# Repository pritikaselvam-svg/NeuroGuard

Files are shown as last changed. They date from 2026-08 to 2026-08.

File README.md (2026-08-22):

# NeuroGuard[README.md](https://github.com/user-attachments/files/31235367/README.md)
# NeuroGuard --- Wearable Alzheimer's Patient Monitoring & Caregiver Support System

NeuroGuard is an interdisciplinary engineering prototype combining
**biological/behavioral reasoning, embedded electronics, PCB design,
software, Android packaging, and wearable CAD**.
## PCB Design

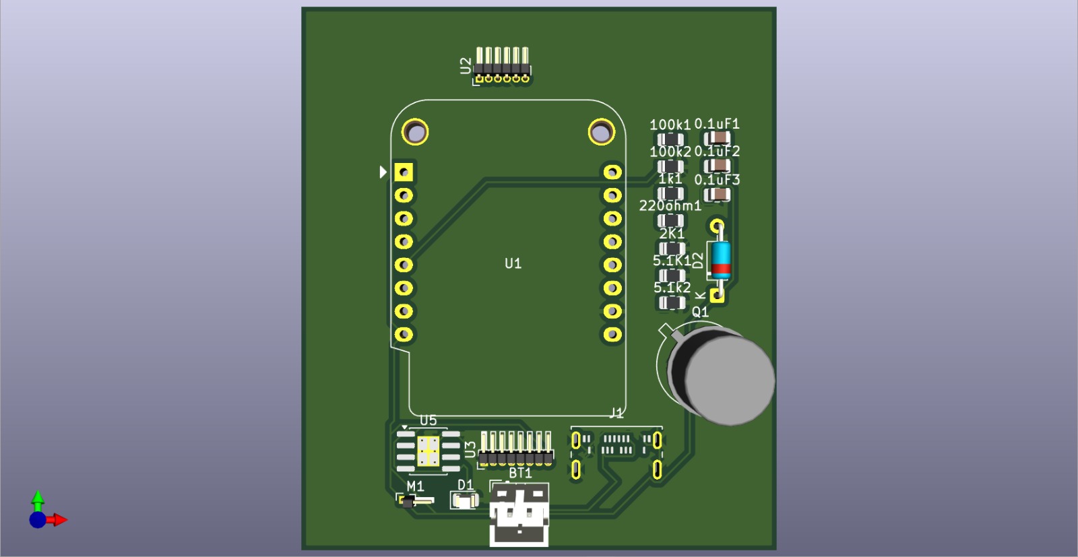
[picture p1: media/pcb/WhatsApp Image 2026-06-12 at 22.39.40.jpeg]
NeuroGuard PCB


> **Current prototype status:** The caregiver application is functional
> in Demo/Simulation Mode. The Android application is a WebView wrapper
> around the HTML/CSS/JavaScript interface. The physical PCB and live
> sensor-to-phone BLE pipeline remain hardware-integration stages.

## What the system is designed to support

-   Heart-rate monitoring using MAX30102.
-   SpO2-related optical measurement capability.
-   Motion/activity monitoring using MPU6050.
-   Fall-event detection logic.
-   Unusual activity / wandering-support logic.
-   Sleep/activity trend estimation.
-   Medication reminders and adherence logging.
-   Haptic alerts through a vibration motor.
-   Battery monitoring.
-   Caregiver dashboard and alerts.

## System architecture

``` text
       BIOLOGICAL / BEHAVIORAL LAYER
                    |
                    v
             Signal selection
                    |
                    v
 MAX30102 ----+                 +---- MPU6050
              |                 |
              +---- ESP32-C3 ---+
                       |
             +---------+---------+
             |         |         |
             v         v         v
          Haptic    Battery     BLE
          Alert     Monitor      |
                                 v
                           Android App
                                 |
                                 v
                          Caregiver UI
```

## Repository structure

``` text
docs/        Research, design decisions, testing and evidence
hardware/    KiCad, Gerbers, BOM and datasheets
firmware/    ESP32-C3 firmware
app/         Web application and Android wrapper
cad/         Wearable enclosure files
data/        Simulated/test data
media/       Portfolio images and diagrams
```

## Important medical boundary

NeuroGuard is a **student engineering prototype, not a medical
diagnostic device**.

The current system must not be described as diagnosing Alzheimer's
disease, infection, dehydration, or another medical condition. In
particular, MAX30102 heart-rate data is a physiological signal, not an
infection detector. The current hardware also does not contain a
dedicated temperature sensor.

## Current versus future implementation

### Current

``` text
Simulated JavaScript data
        ↓
HTML/CSS/JS dashboard
        ↓
Android WebView
```

### Target

``` text
MAX30102 + MPU6050 + battery
             ↓
          ESP32-C3
             ↓
             BLE
             ↓
        Android App
             ↓
       Caregiver UI
```

## Engineering evidence

The repository documents the complete path:

**Problem → research → biological mapping → requirements → component
selection → schematic → PCB → firmware architecture → app → CAD →
testing → limitations → future work.**

## Status

-   [x] Problem definition
-   [x] Biological/behavioral mapping
-   [x] Component selection
-   [x] KiCad schematic
-   [x] PCB routing
-   [x] Web dashboard
-   [x] Simulated sensor layer
-   [x] Android WebView packaging
-   [ ] Physical PCB bring-up
-   [ ] Real sensor validation
-   [ ] ESP32-C3 firmware validation
-   [ ] BLE integration
-   [ ] Enclosure fabrication
-   [ ] Integrated hardware testing
-   [ ] Human/clinical validation

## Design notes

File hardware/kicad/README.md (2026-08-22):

# KiCad Design Files

This folder contains the editable KiCad design files for the NeuroGuard wearable PCB.

## Files

- `NeuroGuard.kicad_sch` — Complete circuit schematic
- `NeuroGuard.kicad_pcb` — PCB layout and routing
- `NeuroGuard.kicad_pro` — KiCad project configuration

## Design

The PCB integrates:

- WEMOS C3 Mini / ESP32-C3
- MAX30102 physiological sensor
- MPU6050 motion sensor
- TP4056 battery charging
- 3.3 V regulation
- Battery voltage monitoring
- Vibration motor driver
- Status LED
- USB-C power input

## Design Verification

The schematic was checked using KiCad Electrical Rules Check (ERC).

The PCB was subsequently routed and checked using KiCad Design Rules Check (DRC).

## Editing

Open the `.kicad_pro` file in KiCad to access the complete project.

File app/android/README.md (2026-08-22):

# NeuroGuard Mobile Application

The NeuroGuard application is the software interface for the wearable Alzheimer's patient monitoring system.

It provides a caregiver-facing dashboard for viewing patient information, monitoring simulated health metrics, identifying abnormal activity and presenting alerts.

> **Current implementation:** The application currently runs using simulated sensor data. Hardware sensor-to-app communication will be integrated in a later stage.

---

## Application Overview

The application is built as a lightweight web-based interface that can also be packaged and deployed as an Android application using Android Studio and a WebView.

The current application consists of:

- HTML — application structure and interface
- CSS — visual design and responsive layout
- JavaScript — application logic and dashboard interactions
- Sensor Service — simulated sensor data generation and processing

---

## Project Files

### `index.html`

The main entry point of the application.

It defines:

- Application layout
- Dashboard structure
- Patient information
- Health metric cards
- Navigation
- Alerts
- Monitoring sections
- Media and visual elements

The HTML file provides the structure that is rendered inside the Android WebView.

---

### `style.css`

Contains the visual styling of the application.

It controls:

- Colours
- Typography
- Cards
- Buttons
- Navigation
- Dashboard layout
- Responsive behaviour
- Spacing
- Icons
- Alerts
- Mobile presentation

The stylesheet allows the same interface to operate as both a web application and a mobile interface.

---

### `app.js`

Contains the main application logic.

Responsibilities include:

- Dashboard updates
- UI interactions
- Navigation
- Updating displayed values
- Alert presentation
- Patient monitoring interface
- Interaction between the interface and sensor data

---

### `sensorService.js`

Handles the sensor-data layer of the application.

Since the physical wearable prototype is currently under development, this service provides **simulated sensor readings** representing the data expected from the wearable.

The simulated data can represent parameters such as:

- Heart rate
- SpO₂
- Activity
- Movement
- Fall events
- Other wearable-derived metrics

This allows the complete application interface and monitoring logic to be demonstrated before the physical ESP32 wearable is connected.

---

# Data Flow

The intended architecture is:

```text
Wearable Sensors
       ↓
   ESP32-C3
       ↓
 Sensor Processing
       ↓
      BLE
       ↓
NeuroGuard Android App
       ↓
Caregiver Dashboard
       ↓
Alerts / Monitoring

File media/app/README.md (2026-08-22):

# app
# NeuroGuard App

NeuroGuard includes a companion mobile application designed to visualize wearable sensor data, monitor patient status and provide caregiver alerts.

## Application Interface

### Dashboard

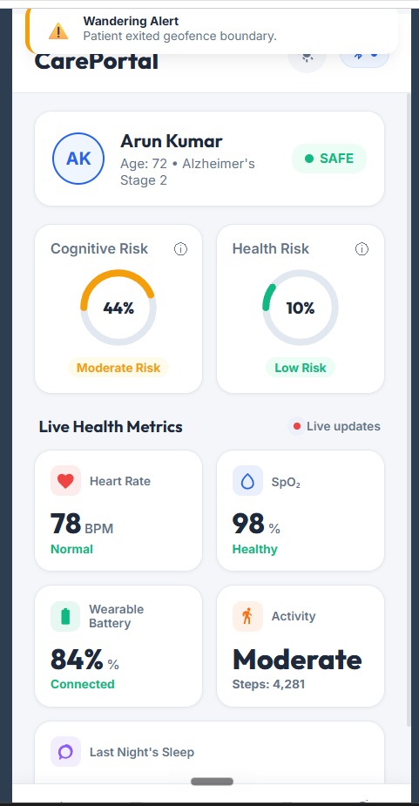
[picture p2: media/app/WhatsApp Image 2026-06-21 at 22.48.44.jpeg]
NeuroGuard App Dashboard


### Patient Monitoring

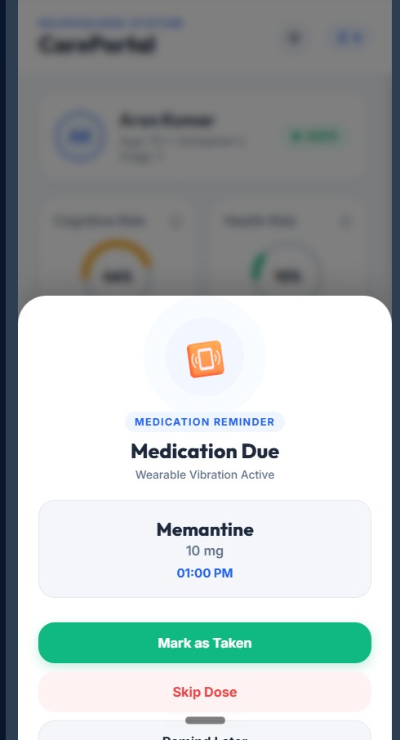
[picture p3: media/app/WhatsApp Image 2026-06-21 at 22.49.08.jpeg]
NeuroGuard Patient Monitoring


### Application Interface

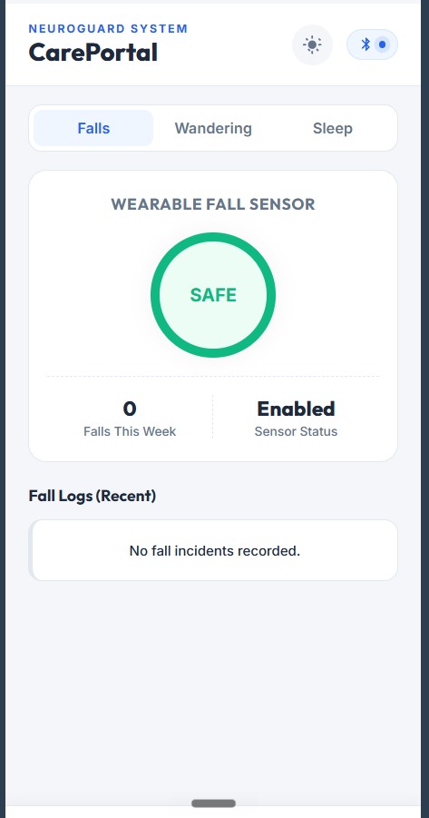
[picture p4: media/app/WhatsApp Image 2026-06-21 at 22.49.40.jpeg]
NeuroGuard App Interface


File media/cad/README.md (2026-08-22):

# cad

# CAD Development

The wearable enclosure was developed with a focus on compactness, component integration, accessibility and comfortable wearable form.

## Modelling Process

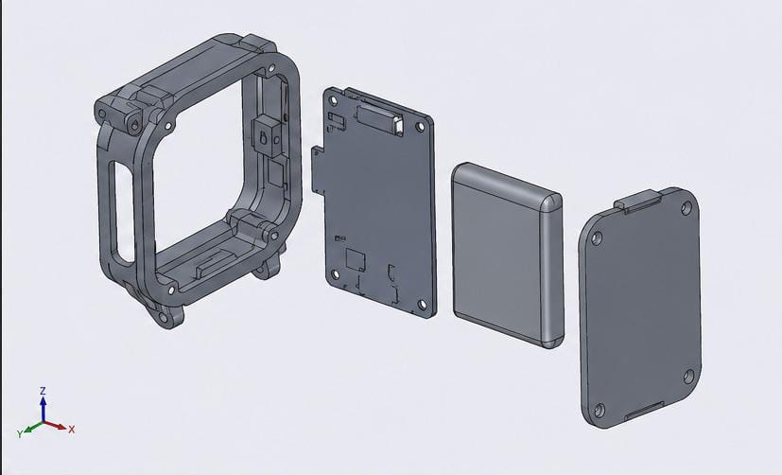
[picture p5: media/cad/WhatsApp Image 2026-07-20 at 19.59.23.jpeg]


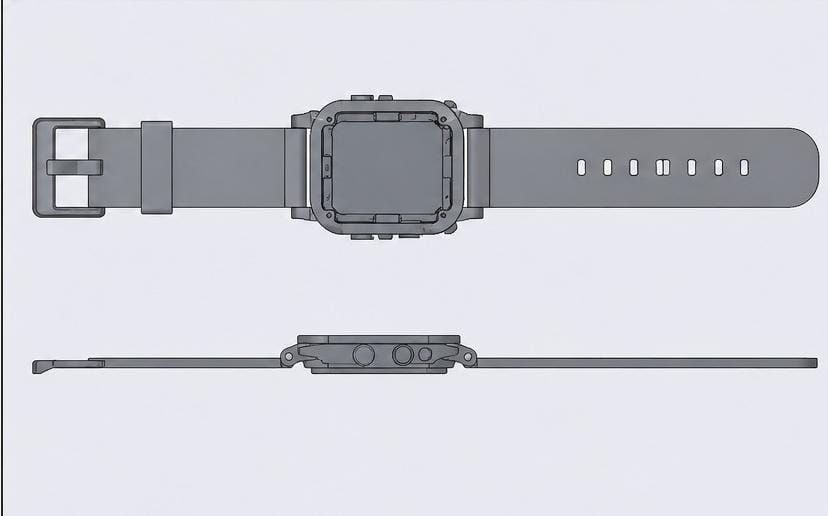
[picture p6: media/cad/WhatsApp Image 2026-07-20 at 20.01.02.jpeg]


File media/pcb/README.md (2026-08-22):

# pcb
# PCB Design

The NeuroGuard PCB integrates the ESP32-C3 Mini, physiological sensing, motion sensing, power management, battery monitoring and wearable alert circuitry into a compact wearable platform.

## PCB Development

### PCB Layout

NeuroGuard PCB Layout

### PCB Routing

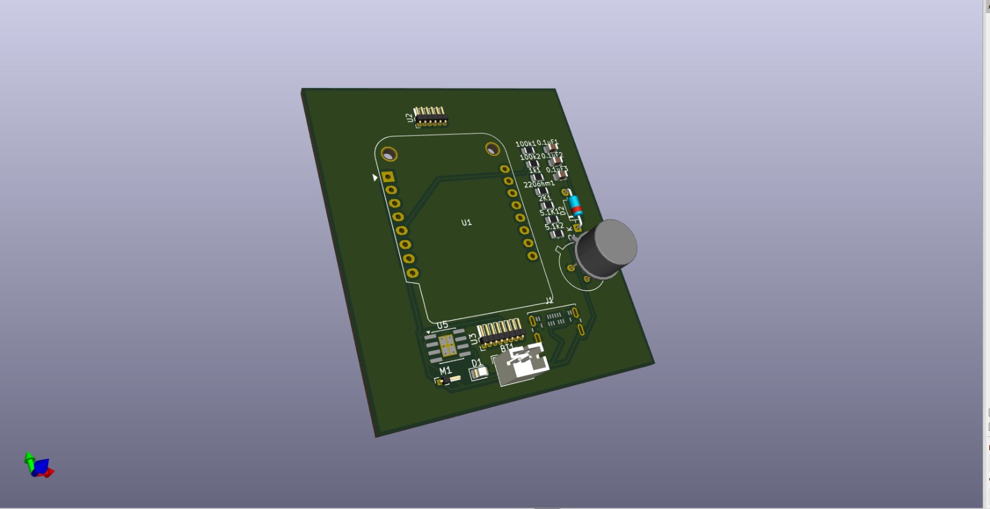
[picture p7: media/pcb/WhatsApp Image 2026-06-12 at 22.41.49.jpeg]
NeuroGuard PCB Routing


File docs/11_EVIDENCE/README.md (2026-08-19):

# Evidence Index

Use this directory for visual proof of development.

``` text
research/    literature and biological mapping
schematic/   KiCad schematic
pcb/         placement, routing, DRC, 3D
firmware/    serial logs and sensor tests
app/         dashboard and Android screenshots
cad/         modelling progression
testing/     measured validation
```

Use descriptive names such as `pcb_05_final_3d.png`, not
`final_final.png`.

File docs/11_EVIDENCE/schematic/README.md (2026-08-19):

# schematic

Add the corresponding project files/evidence here.

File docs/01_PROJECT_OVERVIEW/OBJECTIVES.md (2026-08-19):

# Objectives

## Primary

1.  Design a compact wearable electronics architecture.
2.  Integrate MAX30102 and MPU6050 with an ESP32-C3.
3.  Provide haptic feedback.
4.  Monitor battery voltage.
5.  Develop a caregiver-facing application.
6.  Build a simulated-data pipeline for software validation.
7.  Document the complete engineering process.

## Secondary

-   Keep the architecture low-cost and modular.
-   Minimize wearable volume.
-   Separate sensor drivers from decision logic.
-   Make simulation replaceable by live BLE data.

## Explicit non-objectives

-   Alzheimer's diagnosis.
-   Infection diagnosis.
-   Clinical treatment decisions.
-   Claims of clinical accuracy without validation.

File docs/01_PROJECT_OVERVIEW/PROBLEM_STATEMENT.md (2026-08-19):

# Problem Statement

People living with Alzheimer's disease and related cognitive impairment
may experience changes in movement, sleep/activity patterns, falls,
physiological state and medication adherence. Caregivers may not
continuously observe these changes.

There is an opportunity to explore a compact, low-cost wearable that
combines multiple sensing modalities with caregiver-facing software.

**NeuroGuard proposes a wearable monitoring prototype that integrates
optical physiological sensing, motion sensing, battery monitoring,
haptic feedback and a caregiver application.**

The engineering problem is to convert low-level sensor measurements into
understandable, actionable caregiver information while maintaining a
clear distinction between measurement, inference and medical diagnosis.

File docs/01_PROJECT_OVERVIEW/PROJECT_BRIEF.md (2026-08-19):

# Project Brief

## Concept

NeuroGuard is a compact wearable concept intended to provide caregivers
with continuous observations of selected physiological and movement
signals while supporting medication reminders and event alerts.

## Intended users

-   People living with Alzheimer's disease or related cognitive
    impairment.
-   Family caregivers.
-   Professional caregivers.
-   Student/research teams exploring assistive-health technology.

## Core problem

A caregiver cannot continuously observe a patient's movement,
sleep/activity pattern, physiological state, or medication response. A
wearable can provide an additional stream of observations and alerts.

## Proposed solution

A wrist-worn device combines:

-   WEMOS C3 Mini / ESP32-C3.
-   MAX30102 optical sensor.
-   MPU6050 accelerometer/gyroscope.
-   Battery monitor.
-   Vibration motor.
-   Status LED.
-   Rechargeable Li-ion power system.

The companion application presents the resulting information in a
caregiver-oriented interface.

## Design philosophy

NeuroGuard is a **support system**, not a diagnostic system. It reports
observations, trends and event candidates and clearly identifies
uncertainty.

## Demonstration strategy

Because the physical sensor-to-app pipeline is not yet complete, the
software uses deterministic/randomized simulated values to demonstrate
the complete user workflow before hardware integration.

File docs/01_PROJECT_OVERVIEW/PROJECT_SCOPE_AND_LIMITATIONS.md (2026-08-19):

# Project Scope and Limitations

## In scope

-   Biological/behavioral signal mapping.
-   Sensor selection.
-   Electronics and PCB.
-   Embedded architecture.
-   Haptic feedback.
-   Battery monitoring.
-   Caregiver software.
-   Simulated-data validation.
-   Wearable CAD.

## Current limitations

1.  The app currently uses simulated data.
2.  Real BLE communication is not yet validated.
3.  Physical sensor accuracy has not been established.
4.  Battery life has not been characterized.
5.  No clinical dataset has been used.
6.  No clinical thresholds have been validated.
7.  The current hardware has no temperature sensor.
8.  The enclosure is a prototype concept until physically fabricated.

## Interpretation

A feature is marked **implemented** only when it is actually
demonstrated. A feature marked **planned** must not be presented as a
completed hardware capability.

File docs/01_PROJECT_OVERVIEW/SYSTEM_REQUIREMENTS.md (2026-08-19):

# System Requirements

  ID      Requirement                          Verification
  ------- ------------------------------------ ---------------------
  FR-01   Acquire optical physiological data   Sensor test
  FR-02   Acquire motion data                  IMU test
  FR-03   Process signals using ESP32-C3       Firmware test
  FR-04   Provide haptic notification          Motor test
  FR-05   Monitor battery voltage              ADC test
  FR-06   Support medication reminders         App test
  FR-07   Display trends and alerts            App test
  FR-08   Operate in Demo Mode                 Software test
  FR-09   Define a future BLE interface        Architecture review

## Physical constraints

-   Wrist-worn form factor.
-   Rechargeable single-cell Li-ion.
-   Compact PCB.
-   Sensor-to-skin access.
-   Accessible charging.
-   Safe battery enclosure.

## Safety

The prototype must not be used as a medical decision-making system.
Electrical safety and battery protection must be verified before
physical use.

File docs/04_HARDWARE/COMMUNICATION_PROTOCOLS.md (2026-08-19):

# Communication Protocols

## Current

The app uses local simulated JavaScript data. Live BLE has not yet been
validated.

## Target

``` text
ESP32-C3 → BLE → Android
```

## Suggested data packet

``` json
{
  "timestamp": 0,
  "heartRate": 78,
  "spo2": 98,
  "activity": 0.42,
  "fall": false,
  "battery": 84
}
```

The final BLE UUIDs, packet format and update rate should be defined
before live integration.

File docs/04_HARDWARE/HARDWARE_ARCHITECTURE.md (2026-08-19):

# Hardware Architecture

``` text
USB-C
  ↓
TP4056
  ↓
1-cell Li-ion
  ↓
RT9701
  ↓
3.3 V
  ├── ESP32-C3
  ├── MAX30102
  └── MPU6050

ESP32-C3
  ├── Battery ADC
  ├── Status LED
  ├── 2N2219 → vibration motor
  └── Future BLE
```

## Design intent

The WEMOS C3 Mini is the controller. MAX30102 provides optical sensing.
MPU6050 provides motion sensing. The power stage provides a rechargeable
supply. The motor is driven through a transistor rather than directly
from a GPIO.

## Hardware validation boundary

The architecture is a design artifact until the physical board is
powered and each subsystem is measured.

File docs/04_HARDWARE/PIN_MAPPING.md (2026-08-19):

# Pin Mapping

> The final KiCad schematic is the source of truth. Verify GPIO numbers
> against the exact WEMOS C3 Mini board revision before firmware freeze.

  Function        Current schematic role    Peripheral
  --------------- ------------------------- -------------------------
  I2C SDA         Assigned in schematic     MAX30102 + MPU6050
  I2C SCL         Assigned in schematic     MAX30102 + MPU6050
  Battery ADC     D0 in current schematic   100 kΩ / 100 kΩ divider
  Motor control   Assigned GPIO             1 kΩ → 2N2219
  Status LED      Assigned GPIO             220 Ω → LED
  3.3 V           3V3                       Sensors
  Ground          GND                       Common return

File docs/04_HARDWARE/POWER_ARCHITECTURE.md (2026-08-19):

# Power Architecture

``` text
USB-C VBUS
   ↓
TP4056 charger
   ↓
Li-ion battery
   ↓
RT9701
   ↓
3.3 V rail
```

## Battery divider

Current schematic concept:

``` text
Battery +
   |
100 kΩ
   |
   +---- ADC
   |
100 kΩ
   |
  GND
```

The ADC sees approximately half the battery voltage.

### Validation

Before hardware use, verify:

-   ADC input range.
-   Exact ESP32-C3 ADC behavior.
-   Resistor tolerance.
-   Regulator input range.
-   Peak motor current.
-   Battery protection.
-   Charging configuration.

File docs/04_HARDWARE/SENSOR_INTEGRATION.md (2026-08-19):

# Sensor Integration

## I2C

MAX30102 and MPU6050 can share the I2C bus if their addresses and
electrical requirements are compatible.

``` text
ESP32 SDA ──┬── MAX30102 SDA
            └── MPU6050 SDA

ESP32 SCL ──┬── MAX30102 SCL
            └── MPU6050 SCL
```

Both share 3.3 V and GND.

## Integration sequence

1.  Power rails.
2.  I2C initialization.
3.  Bus scan.
4.  MAX30102 initialization.
5.  MPU6050 initialization.
6.  Raw-data read.
7.  Plausibility check.
8.  Feature extraction.
9.  Event logic.
10. Communication.

A successful I2C read does not prove sensor accuracy.

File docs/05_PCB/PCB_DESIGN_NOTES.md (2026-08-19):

# PCB Design Notes

## Subsystems

-   ESP32-C3 module.
-   MAX30102.
-   MPU6050.
-   USB-C charging.
-   TP4056.
-   Li-ion battery.
-   3.3 V regulation.
-   Battery ADC.
-   Haptic driver.
-   Status LED.

## Layout priorities

1.  Compact wearable footprint.
2.  Practical sensor placement.
3.  Short sensitive signal paths.
4.  Local decoupling.
5.  Compact motor-current path.
6.  Accessible charging connection.
7.  Manufacturable clearances.

## Final review

-   [ ] Exact footprints verified.
-   [ ] Board outline verified.
-   [ ] Silkscreen checked.
-   [ ] DRC checked.
-   [ ] Gerbers generated.
-   [ ] Drill files generated.
-   [ ] BOM generated.

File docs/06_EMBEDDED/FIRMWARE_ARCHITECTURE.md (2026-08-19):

# Firmware Architecture

``` text
BOOT
 ↓
GPIO
 ↓
I2C
 ↓
MAX30102 + MPU6050
 ↓
Battery ADC
 ↓
BLE initialization
 ↓
Sensor acquisition
 ↓
Filtering/features
 ↓
Event logic
 ↓
Haptic/LED
 ↓
BLE packet
 ↓
Repeat
```

Recommended modules:

``` text
main
sensor_max30102
sensor_mpu6050
battery
alerts
motor
status_led
ble
data_model
```

Keep hardware drivers separate from event logic.

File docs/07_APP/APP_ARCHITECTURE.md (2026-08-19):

# Application Architecture

``` text
index.html
  ├── style.css
  ├── app.js
  └── sensor.js
          ↓
   simulated data layer
          ↓
      app state
          ↓
          UI
```

Android wrapper:

``` text
MainActivity.kt
      ↓
    WebView
      ↓
file:///android_asset/index.html
```

Future:

``` text
BLE → SensorDataService → App State → UI
```

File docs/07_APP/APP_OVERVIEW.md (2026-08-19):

# Application Overview

The NeuroGuard caregiver app is a mobile-friendly HTML/CSS/JavaScript
interface.

## Main features

-   Patient dashboard.
-   Live-style health metrics.
-   Cognitive-risk visualization.
-   Health-risk visualization.
-   Fall events.
-   Activity/wandering-support events.
-   Sleep/activity trends.
-   Medication management.
-   Alert center.
-   Caregiver information.
-   Device status.

## Demo mode

The app generates simulated values so that the user experience can be
demonstrated before live hardware integration.

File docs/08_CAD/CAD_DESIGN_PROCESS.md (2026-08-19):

# CAD Design Process

## Goal

Create a compact wrist-worn enclosure for the PCB, battery, sensors,
motor and strap.

## Process

``` text
Requirements
→ PCB envelope
→ component packaging
→ outer form
→ sensor contact
→ battery cavity
→ motor clearance
→ back cover
→ strap interface
→ assembly check
```

## Design evidence

Upload actual modelling screenshots showing the progression. Concept
renders should be labelled as concept visuals.

## Key constraints

-   PCB dimensions.
-   Battery thickness.
-   Sensor-to-skin contact.
-   Motor clearance.
-   USB access.
-   Assembly.
-   Strap geometry.
-   Comfort.

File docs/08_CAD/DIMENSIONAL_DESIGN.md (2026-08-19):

# Dimensional Design

Record final dimensions from actual components:

-   PCB length/width/thickness.
-   Battery length/width/thickness.
-   Motor diameter/height.
-   Sensor clearance.
-   Wall thickness.
-   Standoff height.
-   Strap width.

Do not label estimated CAD dimensions as manufacturing-ready dimensions.

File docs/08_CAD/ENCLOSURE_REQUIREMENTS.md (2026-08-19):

# Enclosure Requirements

  Requirement              Reason
  ------------------------ --------------------
  Compact                  Wearability
  Rounded edges            Comfort
  Sensor contact/opening   Optical sensing
  PCB standoffs            Mechanical support
  Battery clearance        Safety
  Motor clearance          Vibration
  Charging access          Usability
  Strap attachment         Retention
  Serviceability           Iteration

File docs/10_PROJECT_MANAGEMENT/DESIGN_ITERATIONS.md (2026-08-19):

# Design Iterations

### Iteration 1

Wearable concept for Alzheimer's caregiver support.

### Iteration 2

Selected MAX30102, MPU6050 and ESP32-C3.

### Iteration 3

Added TP4056, Li-ion battery, RT9701 and battery monitoring.

### Iteration 4

Added transistor-driven vibration motor and status LED.

### Iteration 5

Built software around simulated sensor data.

### Iteration 6

Packaged the web app as an Android WebView.

### Next

Physical bring-up → firmware → BLE → live data → enclosure validation.

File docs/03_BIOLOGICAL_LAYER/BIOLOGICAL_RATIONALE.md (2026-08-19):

# Biological Rationale

NeuroGuard starts from the question: **what caregiver-relevant changes
can be observed non-invasively?**

``` text
Patient physiology/behavior
        ↓
Observable signal
        ↓
Sensor
        ↓
Feature
        ↓
Event/trend
        ↓
Caregiver information
```

### Movement

Acceleration and angular velocity can represent activity and sudden
events.

### Heart rate

Pulse rate is a measurable physiological variable but is highly
non-specific.

### SpO2-related measurement

The MAX30102 provides optical signals from which pulse and
oxygen-saturation-related estimates can be produced. Accuracy must be
validated before clinical interpretation.

### Medication adherence

The current system treats adherence as a software event: reminder →
response → log.

### Infection-related monitoring

The current hardware does not contain a temperature sensor. Therefore it
cannot claim temperature measurement or infection detection. Heart-rate
elevation is only an indirect physiological indicator.

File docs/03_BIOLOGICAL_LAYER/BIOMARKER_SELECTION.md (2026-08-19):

# Signal / Biomarker Selection

  --------------------------------------------------------------------------
  Signal            Rationale            Sensor            Limitation
  ----------------- -------------------- ----------------- -----------------
  Heart rate        Non-invasive         MAX30102          Non-specific
                    physiological                          
                    observation                            

  SpO2-related      Additional           MAX30102          Requires
  optical signal    physiological                          validation
                    context                                

  Acceleration      Activity/fall events MPU6050           False positives
                                                           possible

  Gyroscope         Orientation/motion   MPU6050           Drift/noise
                    context                                

  Battery voltage   Device reliability   Divider + ADC     Calibration
                                                           required

  Medication        Adherence support    App               Self/caregiver
  response                                                 reported
  --------------------------------------------------------------------------

The selection principle is: **every sensor must answer a defined
question.**

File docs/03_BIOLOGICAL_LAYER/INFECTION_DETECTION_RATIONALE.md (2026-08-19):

# Infection-Related Monitoring Rationale

## Current position

NeuroGuard should **not** be described as an infection detector.

The current hardware has MAX30102 but no dedicated temperature sensor.
Heart-rate elevation is non-specific and may have many causes.

### Preferred wording

Use:

-   "physiological change alert"
-   "possible health deterioration"
-   "elevated heart-rate indicator"

Avoid:

-   "infection detected"
-   "infection diagnosis"
-   "fever detected"

unless a validated temperature sensor is actually integrated and
appropriately evaluated.

## Future extension

A future revision may add skin-contact temperature sensing, but
temperature alone would still not establish infection.

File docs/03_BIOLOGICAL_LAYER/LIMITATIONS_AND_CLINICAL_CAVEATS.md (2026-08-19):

# Clinical Caveats and Limitations

1.  NeuroGuard is not a medical device.
2.  No diagnosis is produced.
3.  Heart rate is non-specific.
4.  SpO2 estimates require validation.
5.  Motion-based events can produce false positives/negatives.
6.  Wandering classification requires context and ideally location
    information.
7.  Sleep is currently an activity proxy.
8.  Medication adherence is recorded through a software workflow.
9.  Infection is not detected by the current sensor set.
10. Human testing requires appropriate safety, ethics and consent
    procedures.

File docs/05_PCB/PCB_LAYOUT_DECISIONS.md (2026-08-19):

# PCB Layout Decisions

The WEMOS C3 Mini is the main placement anchor because of its module
size and antenna/keep-out considerations.

The optical sensor should be positioned to permit skin contact. The
MPU6050 should be mechanically stable to produce predictable motion
data.

Power components are grouped around USB-C, charging and regulation. The
vibration motor driver should have a compact high-current path and
should be kept away from the most sensitive sensor area where practical.

The final enclosure must be checked against the actual assembled PCB,
not only the schematic.

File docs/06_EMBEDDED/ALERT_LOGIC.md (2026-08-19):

# Alert Logic

  Event                  Source         Output
  ---------------------- -------------- -----------------
  Medication reminder    App schedule   Vibration + app
  Fall candidate         MPU6050        Alert
  Unusual activity       MPU6050        Flag
  Physiological change   MAX30102       Flag
  Low battery            ADC            Warning

Alerts should eventually have severity levels and an acknowledgement
workflow.

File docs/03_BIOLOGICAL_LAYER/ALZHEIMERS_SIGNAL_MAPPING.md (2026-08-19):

# Alzheimer's Signal Mapping

## Wandering support

``` text
Motion samples
→ activity intensity
→ time-of-day context
→ unusual movement pattern
→ caregiver flag
```

## Fall candidate

``` text
Acceleration
→ spike
→ orientation change
→ post-event inactivity
→ candidate fall
```

## Sleep/activity proxy

``` text
Night-time movement
→ activity windows
→ nightly trend
```

## Physiological observation

``` text
Optical waveform
→ pulse estimate
→ HR trend
→ deviation flag
```

## Medication

``` text
Schedule
→ haptic reminder
→ response
→ adherence record
```

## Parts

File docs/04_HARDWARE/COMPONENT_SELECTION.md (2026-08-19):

# Component Selection

  Ref   Selected part          Purpose                          Why
  ----- ---------------------- -------------------------------- ----------------------------
  U1    WEMOS C3 Mini          MCU/wireless                     Compact ESP32-C3 platform
  U2    MAX30102               Optical sensing                  HR/SpO2-related sensing
  U3    MPU6050                Motion                           Accelerometer + gyroscope
  U5    TP4056-42-ESOP8        Charging                         Single-cell Li-ion charger
  U6    RT9701                 Regulation                       3.3 V rail
  Q1    2N2219                 Motor switch                     Low-side switching
  M1    Coin vibration motor   Haptic                           Compact feedback
  D1    LED                    Status                           Visual indication
  D2    1N4148                 Flyback path in current design   Compact diode
  J1    USB-C power-only       Charging input                   Compact
  BT1   1-cell Li-ion          Energy                           Rechargeable

### Footprint rule

Before fabrication, compare every footprint against the exact purchased
component mechanical drawing.

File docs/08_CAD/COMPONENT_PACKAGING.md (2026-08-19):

# Component Packaging

## Packaging concept

``` text
Skin-facing
└── Optical sensor contact region

Main electronics
└── ESP32-C3
└── MAX30102
└── MPU6050
└── Power electronics

Battery cavity
└── Li-ion cell

Haptic/charging
└── Motor
└── USB-C access
```

The final package must be checked against measured components and the
fabricated PCB.

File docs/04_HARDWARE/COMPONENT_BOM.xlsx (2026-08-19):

Ref | Component | Selected Part | Qty | Purpose | Footprint / Package | Status
U1 | MCU | WEMOS C3 Mini | 1 | ESP32-C3 processing + wireless | RF_Module:WEMOS_C3_mini | Designed
U2 | Optical sensor | MAX30102 | 1 | HR / SpO2-related sensing | Maxim OLGA-14 class | Designed
U3 | IMU | MPU-6050 | 1 | Acceleration + gyroscope | InvenSense QFN-24 class | Designed
U5 | Charger | TP4056-42-ESOP8 | 1 | Li-ion charging | SOIC-8-1EP class | Designed
U6 | Regulator | RT9701 | 1 | 3.3 V regulation | Verify exact package | Designed
Q1 | Transistor | 2N2219 | 1 | Motor switching | TO-39-3 | Designed
M1 | Vibration motor | Coin motor | 1 | Haptic feedback | Verify vendor footprint | Designed
D1 | LED | LED | 1 | Status indication | Verify exact LED footprint | Designed
D2 | Diode | 1N4148 | 1 | Flyback path in current design | DO-35 class | Designed
J1 | USB-C | Power-only USB-C | 1 | Charging input | USB_C_Receptacle_PowerOnly_6P | Designed
BT1 | Battery | 1-cell Li-ion | 1 | Energy storage | Verify cell/connector | Verify
R1 | Resistor | 100 kΩ | 1 | Battery divider | Verify package | Designed
R2 | Resistor | 100 kΩ | 1 | Battery divider | Verify package | Designed
R3 | Resistor | 220 Ω | 1 | LED current limit | Verify package | Designed
R4 | Resistor | 1 kΩ | 1 | Motor base resistor | Verify package | Designed
R5 | Resistor | 2 kΩ | 1 | TP4056 PROG setting | Verify package | Designed
R6 | Resistor | 5.1 kΩ | 1 | USB-C CC1 pulldown | Verify package | Designed
R7 | Resistor | 5.1 kΩ | 1 | USB-C CC2 pulldown | Verify package | Designed
C1 | Capacitor | 0.1 µF | 1 | Decoupling | Verify package | Designed
C2 | Capacitor | 0.1 µF | 1 | Decoupling | Verify package | Designed
C3 | Capacitor | 0.1 µF | 1 | Decoupling | Verify package | Designed

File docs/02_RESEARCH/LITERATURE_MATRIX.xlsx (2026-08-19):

ID | Citation | Year | Population | Condition | Sensor | Signal | Method/Algorithm | Outcome | Validation | Key Finding | Limitation | Relevance | DOI/URL
P001 |  |  |  |  | IMU | Acceleration |  | Fall detection
P002 |  |  |  |  | PPG | Heart rate |  | Physiological monitoring
P003 |  |  |  |  | IMU | Activity |  | Sleep/activity proxy
P004 |  |  |  |  | Wearable | Adherence |  | Medication support

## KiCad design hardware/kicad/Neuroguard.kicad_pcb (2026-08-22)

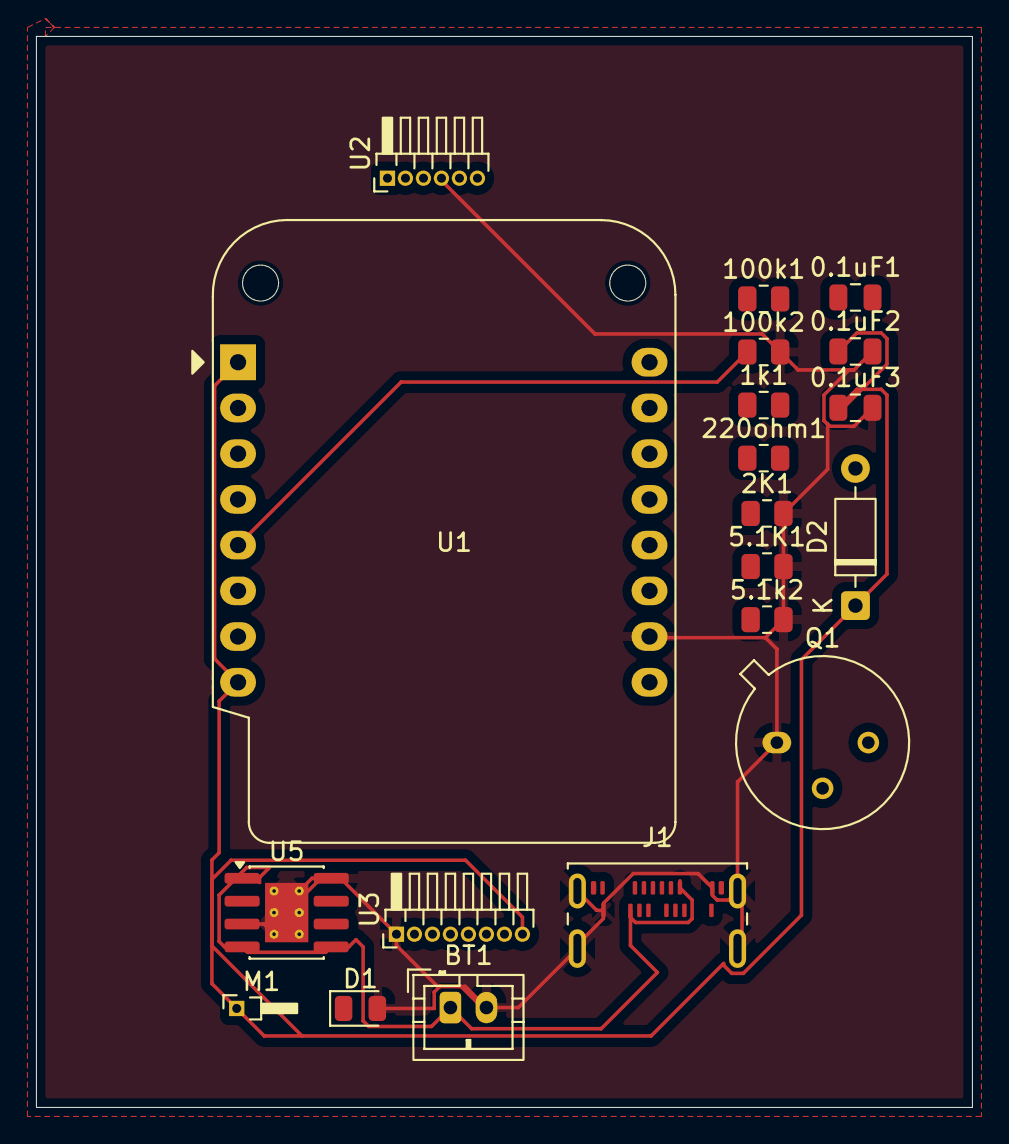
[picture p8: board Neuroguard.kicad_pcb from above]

Board: 2 copper layers, 52.0 x 59.5 mm, 20 parts (0 on the bottom side), 4 nets.

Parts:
0.1uF1, 0.1uF2, 0.1uF3: C; C_0805_2012Metric
1k1, 2K1, 5.1K1, 5.1k2, 100k1, 100k2, 220ohm1: R; R_0805_2012Metric
BT1: Battery; JST_PH_B2B-PH-K_1x02_P2.00mm_Vertical
D1: LED; LED_0805_2012Metric
D2: 1N4148; D_DO-35_SOD27_P7.62mm_Horizontal
J1: USB_C_Receptacle_PowerOnly_6P; USB_C_Receptacle_Amphenol_124019772112A
M1: Motor_DC; PinHeader_1x01_P1.00mm_Horizontal
Q1: 2N2219; TO-39-3
U1: WEMOS_C3_mini
U2: MAX30102; PinHeader_1x06_P1.00mm_Horizontal
U3: MPU-6050; PinHeader_1x08_P1.00mm_Horizontal
U5: TP4056-42-ESOP8; SOIC-8-1EP_3.9x4.9mm_P1.27mm_EP2.41x3.3mm_ThermalVias

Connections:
GND: 0.1uF2.2, 0.1uF3.2, 2K1.2, 5.1K1.2, 5.1k2.2, 100k2.2, BT1.2 (-), D1.2 (A), J1.A12 (GND), J1.B12 (GND), J1.S1 (SHIELD), Q1.1 (E), U1.10 (GND), U2.4 (PGND), U3.1 (CLKIN), U5.3 (GND), U5.8 (CE), U5.9 (EPAD)
unnamed: BT1.1 (+), J1.A9 (VBUS), J1.B9 (VBUS), U5.1 (TEMP), U5.4 (V_{CC}), U5.5 (BAT)
unnamed: 0.1uF2.1, 0.1uF3.1, D2.1 (K), M1.1 (+), U1.1 (EN), U1.8 (3V3), U3.8 (VLOGIC)
unnamed: 100k2.1, U1.5 (D0)

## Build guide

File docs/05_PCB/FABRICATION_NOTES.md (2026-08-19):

# Fabrication Notes

## Manufacturing package

-   Gerbers.
-   Drill files.
-   Board outline.
-   BOM.
-   Assembly drawing.
-   Pick-and-place data if required.

## Before ordering

Verify board thickness, copper, clearances, hole sizes, solder mask,
surface finish, component availability and footprints.

## Suggested assembly order

1.  Small passives.
2.  Sensors.
3.  Charger/regulator.
4.  Transistor/diode/LED.
5.  WEMOS C3 Mini.
6.  Connectors.
7.  Battery/motor interfaces.
8.  Inspection.
9.  Power-up.

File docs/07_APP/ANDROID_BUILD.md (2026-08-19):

# Android Build

The application is packaged as an Android WebView project in Android
Studio.

## Assets

``` text
app/src/main/assets/
├── index.html
├── style.css
├── app.js
└── sensor.js
```

## MainActivity

The Kotlin activity loads:

``` text
file:///android_asset/index.html
```

and enables JavaScript for the web application.

## Build

``` text
Build
→ Generate App Bundles or APKs
→ Build APKs
```

The debug APK is normally found under:

``` text
app/build/outputs/apk/debug/
```

## Current evidence

The app has been successfully demonstrated in an Android emulator.

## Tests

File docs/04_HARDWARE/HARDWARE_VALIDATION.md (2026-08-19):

# Hardware Validation

## Bring-up order

1.  Visual inspection.
2.  Continuity/short check.
3.  USB-C input.
4.  TP4056 charging behavior.
5.  Battery voltage.
6.  3.3 V regulator.
7.  ESP32-C3 boot.
8.  I2C scan.
9.  MAX30102.
10. MPU6050.
11. Motor.
12. Battery ADC.
13. LED.
14. Integrated firmware.

For every test record date, instrument, condition, expected result,
measured result and pass/fail.

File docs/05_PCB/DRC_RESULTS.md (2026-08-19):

# DRC / ERC Results

The schematic review reached **zero reported ERC violations** during the
documented review stage.

The PCB routing stage was subsequently completed.

A clean ERC/DRC result means the design satisfies configured
electrical/design rules; it does not prove functional correctness.

Attach final screenshots to `docs/11_EVIDENCE/pcb/` before fabrication.

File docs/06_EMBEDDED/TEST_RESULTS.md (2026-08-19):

# Firmware Test Results

  Module     Test          Expected             Status
  ---------- ------------- -------------------- ---------
  I2C        Bus scan      Devices respond      Pending
  MAX30102   Init          Successful           Pending
  MAX30102   Signal        Plausible waveform   Pending
  MPU6050    Init          Successful           Pending
  MPU6050    Motion        Values change        Pending
  Motor      GPIO          Vibration            Pending
  Battery    ADC           Plausible voltage    Pending
  BLE        Advertising   Phone discovers      Pending

Replace "Pending" only after measured testing.

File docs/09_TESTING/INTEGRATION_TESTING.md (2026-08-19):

# Integration Testing

## Current

Software integration is complete for simulated data.

## Future

``` text
Sensors → ESP32-C3 → BLE → Android → Dashboard
```

Test each boundary independently before full-system integration.

## Acceptance criterion

A live sensor value should reach the app with timestamp/source metadata
and the app should visibly distinguish live mode from simulation mode.

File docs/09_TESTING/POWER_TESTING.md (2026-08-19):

# Power Testing

  Condition          Battery V   3.3 V   Current Notes
  ---------------- ----------- ------- --------- -------
  Idle                                           
  Sensors active                                 
  BLE active                                     
  Motor active                                   
  Charging                                       

Use measured values to calculate realistic battery life.

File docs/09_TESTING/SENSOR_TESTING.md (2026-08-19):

# Sensor Testing

## MAX30102

Record supply, I2C response, raw waveform, HR estimate and test
condition.

## MPU6050

Record supply, I2C response, static acceleration, movement response and
orientation.

## Rule

Record raw measurements and test conditions. Screenshots of expected
values are not a substitute for measurements.

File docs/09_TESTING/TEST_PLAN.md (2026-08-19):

# Test Plan

## Electrical

-   [ ] Visual inspection.
-   [ ] Continuity.
-   [ ] Short check.
-   [ ] 3.3 V rail.
-   [ ] Charging.
-   [ ] Regulator.
-   [ ] Battery ADC.

## Sensors

-   [ ] MAX30102 detection.
-   [ ] Optical waveform.
-   [ ] HR plausibility.
-   [ ] MPU6050 detection.
-   [ ] Accelerometer.
-   [ ] Gyroscope.

## Actuator

-   [ ] Motor activation.
-   [ ] Motor current.
-   [ ] Haptic patterns.

## Software

-   [x] Dashboard loads.
-   [x] Simulated values update.
-   [x] Android emulator launch.
-   [ ] Live BLE.
-   [ ] Real sensor display.

## Integration

-   [ ] Wearable → BLE → Android.
-   [ ] Alert event.
-   [ ] Medication reminder.
-   [ ] Battery warning.

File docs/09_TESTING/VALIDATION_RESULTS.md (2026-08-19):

# Validation Results

## Completed evidence

-   Schematic ERC reached zero reported violations during the documented
    review.
-   PCB routing was completed.
-   HTML/CSS/JavaScript dashboard runs in simulation mode.
-   Android WebView application runs in an emulator.
-   Android debug build completed successfully.

## Pending

-   Physical PCB bring-up.
-   Sensor accuracy.
-   Power consumption.
-   Motor current.
-   Battery life.
-   BLE.
-   Real sensor-to-app integration.
-   Enclosure fit.
-   Wearability.

Only replace "pending" with measured evidence after testing.

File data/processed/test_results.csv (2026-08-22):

test_id | subsystem | test | expected | actual | status | notes
T001 | App | Android emulator launch | Dashboard appears | Dashboard appears | PASS | Demo mode
T002 | App | JavaScript execution | Data updates | Data updates | PASS | Local assets
T003 | Schematic | ERC | 0 violations | 0 reported violations | PASS | Documented schematic review
T004 | PCB | Routing | Completed | Completed | PASS | Attached final DRC evidence
T005 | Hardware | MAX30102 bring-up | Sensor responds | Not tested | PENDING | Physical board required
T006 | Hardware | MPU6050 bring-up | Sensor responds | Not tested | PENDING | Physical board required
T007 | Integration | BLE | Live data received | Not implemented | PENDING | Future work

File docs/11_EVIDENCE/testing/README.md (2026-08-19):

# testing

Add the corresponding project files/evidence here.

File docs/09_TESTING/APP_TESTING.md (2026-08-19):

# Application Testing

  Feature      Test              Expected
  ------------ ----------------- -------------------
  Dashboard    Launch            Dashboard appears
  HR           Simulate change   Value updates
  SpO2         Simulate change   Value updates
  Fall         Trigger event     Alert appears
  Activity     Trigger event     Event appears
  Medication   Add dose          Schedule appears
  Reminder     Trigger           Reminder appears
  Battery      Low value         Warning appears

The application has been demonstrated successfully in an Android
emulator.

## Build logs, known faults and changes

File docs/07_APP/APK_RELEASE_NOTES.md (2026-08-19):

# APK Release Notes

## v0.1 Demo

### Included

-   Caregiver dashboard.
-   Simulated sensor data.
-   Risk indicators.
-   Medication workflow.
-   Alerts.
-   Android WebView packaging.

### Not included

-   Verified live BLE.
-   Physical sensor integration.
-   Clinical validation.
-   Production security/certification.

For public release, use a signed release build rather than the debug
APK.

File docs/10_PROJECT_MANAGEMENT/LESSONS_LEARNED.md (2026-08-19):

# Lessons Learned

-   Schematic correctness and physical correctness are different.
-   Footprints must match the purchased parts.
-   ERC/DRC verifies configured rules, not system function.
-   Power should be validated before sensors.
-   A sensor abstraction layer makes software simulation useful.
-   WebView can rapidly package an existing web interface into Android.
-   Biological interpretation must precede sensor selection.
-   Measurements, inferred risks and diagnoses must remain clearly
    separated.

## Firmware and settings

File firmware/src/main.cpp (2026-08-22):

#include <Arduino.h>
#include <Wire.h>

#include <Adafruit_MPU6050.h>
#include <Adafruit_Sensor.h>
#include <MAX30105.h>

#include "../include/config.h"

// =====================================
// SENSOR OBJECTS
// =====================================

Adafruit_MPU6050 mpu;
MAX30105 max30102;

// =====================================
// VARIABLES
// =====================================

float heartRate = 0;
float spo2 = 0;

float accelX = 0;
float accelY = 0;
float accelZ = 0;

float batteryVoltage = 0;

unsigned long lastSensorRead = 0;

// =====================================
// VIBRATION
// =====================================

void vibrate(int duration)
{
    digitalWrite(VIBRATION_PIN, HIGH);
    delay(duration);
    digitalWrite(VIBRATION_PIN, LOW);
}

// =====================================
// BATTERY MONITORING
// =====================================

float readBatteryVoltage()
{
    int raw = analogRead(BATTERY_ADC_PIN);

    float adcVoltage =
        ((float)raw / 4095.0) * ADC_REFERENCE;

    // Voltage divider:
    // Vout = Vin * R2 / (R1 + R2)
    float battery =
        adcVoltage * ((R1 + R2) / R2);

    return battery;
}

// =====================================
// MPU6050
// =====================================

void readMotion()
{
    sensors_event_t acceleration;
    sensors_event_t gyro;
    sensors_event_t temperature;

    mpu.getEvent(
        &acceleration,
        &gyro,
        &temperature
    );

    accelX = acceleration.acceleration.x;
    accelY = acceleration.acceleration.y;
    accelZ = acceleration.acceleration.z;

    float totalAcceleration =
        sqrt(
            accelX * accelX +
            accelY * accelY +
            accelZ * accelZ
        );

    Serial.print("Acceleration: ");
    Serial.println(totalAcceleration);

    // Simple prototype fall detection
    if (totalAcceleration > FALL_ACCEL_THRESHOLD * 9.81)
    {
        Serial.println("⚠ POTENTIAL FALL DETECTED");

        vibrate(VIBRATION_DURATION);
    }
}

// =====================================
// MAX30102
// =====================================

void readHeartSensor()
{
    long irValue = max30102.getIR();

    Serial.print("IR: ");
    Serial.println(irValue);

    /*
       NOTE:

       The MAX30102 raw IR signal is available here.

       Actual heart-rate and SpO2 calculation
       should be implemented using a proper
       MAX30102 algorithm/library once the
       physical sensor is connected and tested.
    */

    if (irValue < 50000)
    {
        Serial.println("No finger / poor contact");
        return;
    }

    // Placeholder values for current prototype
    heartRate = 78;
    spo2 = 98;

    Serial.print("Heart Rate: ");
    Serial.println(heartRate);

    Serial.print("SpO2: ");
    Serial.println(spo2);
}

// =====================================
// HEALTH ALERTS
// =====================================

void checkHealthAlerts()
{
    if (heartRate < HEART_RATE_LOW ||
        heartRate > HEART_RATE_HIGH)
    {
        Serial.println("⚠ ABNORMAL HEART RATE");

        vibrate(VIBRATION_DURATION);
    }

    if (spo2 < SPO2_LOW)
    {
        Serial.println("⚠ LOW SpO2");

        vibrate(VIBRATION_DURATION);
    }
}

// =====================================
// SETUP
// =====================================

void setup()
{
    Serial.begin(115200);

    delay(1000);

    Serial.println();
    Serial.println("==============================");
    Serial.println("      NEUROGUARD DEVICE");
    Serial.println("==============================");

    // GPIO
    pinMode(VIBRATION_PIN, OUTPUT);
    pinMode(STATUS_LED_PIN, OUTPUT);

    digitalWrite(VIBRATION_PIN, LOW);
    digitalWrite(STATUS_LED_PIN, LOW);

    // =================================
    // I2C
    // =================================

    Wire.begin(
        I2C_SDA,
        I2C_SCL
    );

    Serial.println("I2C initialized");

    // =================================
    // MPU6050
    // =================================

    if (!mpu.begin(MPU6050_ADDRESS, &Wire))
    {
        Serial.println("ERROR: MPU6050 not detected!");

        while (1)
        {
            digitalWrite(STATUS_LED_PIN, !digitalRead(STATUS_LED_PIN));
            delay(500);
        }
    }

    Serial.println("MPU6050 detected");

    // Configure MPU6050

    mpu.setAccelerometerRange(
        MPU6050_RANGE_8_G
    );

    mpu.setGyroRange(
        MPU6050_RANGE_500_DEG
    );

    // =================================
    // MAX30102
    // =================================

    if (!max30102.begin(
            Wire,
            I2C_SPEED_FAST,
            MAX30102_ADDRESS))
    {
        Serial.println("ERROR: MAX30102 not detected!");

        while (1)
        {
            digitalWrite(STATUS_LED_PIN, !digitalRead(STATUS_LED_PIN));
            delay(250);
        }
    }

    Serial.println("MAX30102 detected");

    // Configure MAX30102

    max30102.setup();

    max30102.setPulseAmplitudeRed(0x0A);
    max30102.setPulseAmplitudeIR(0x0A);

    // =================================
    // READY
    // =================================

    digitalWrite(STATUS_LED_PIN, HIGH);

    Serial.println("NeuroGuard system ready.");

    vibrate(200);
}

// =====================================
// LOOP
// =====================================

void loop()
{
    if (millis() - lastSensorRead >= 1000)
    {
        lastSensorRead = millis();

        Serial.println();
        Serial.println("---------- SENSOR DATA ----------");

        // Read sensors
        readHeartSensor();

        readMotion();

        // Battery
        batteryVoltage =
            readBatteryVoltage();

        Serial.print("Battery: ");
        Serial.print(batteryVoltage);
        Serial.println(" V");

        // Alerts
        checkHealthAlerts();

        Serial.println("--------------------------------");
    }

    delay(10);
}

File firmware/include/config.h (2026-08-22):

#ifndef NEUROGUARD_CONFIG_H
#define NEUROGUARD_CONFIG_H

// ===============================
// NeuroGuard ESP32-C3 Configuration
// ===============================

// ---------- I2C ----------
// Based on the current schematic
#define I2C_SDA 8
#define I2C_SCL 10

// ---------- Vibration Motor ----------
#define VIBRATION_PIN 3

// ---------- Status LED ----------
#define STATUS_LED_PIN 4

// ---------- Battery Monitoring ----------
#define BATTERY_ADC_PIN 0

// Battery divider:
// Battery -> 100k -> ADC -> 100k -> GND
#define R1 100000.0
#define R2 100000.0

// ESP32-C3 ADC reference approximation
#define ADC_REFERENCE 3.3

// ---------- Sensor Addresses ----------

#define MAX30102_ADDRESS 0x57
#define MPU6050_ADDRESS 0x68

// ---------- Monitoring thresholds ----------

#define HEART_RATE_LOW 50
#define HEART_RATE_HIGH 120

#define SPO2_LOW 90

// Fall detection threshold
#define FALL_ACCEL_THRESHOLD 2.5

// Vibration duration
#define VIBRATION_DURATION 500

#endif
